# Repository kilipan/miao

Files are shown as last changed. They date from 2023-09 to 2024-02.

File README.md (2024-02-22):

# MIAO (喵) ch552t MCU board

### Changelog
2023-09-29 initial commit  
2023-09-30 fixed pinout to correspond to Xiao, added jumper to choose between RX/CS on pin 8, completely rerouted

| :zap: The hardware design is tested and confirmed working as of the latest commit. Nevertheless I cannot guarantee anything. **Use at your own risk!** |
|---|

## About
MIAO is a cheap drop-in replacement for the Seeeduino Xiao series.

喵 is the Hanzi for "miāo", which is Mandarin for "meow".

The board is available in two variants:
- A super cheap, hand-solderable version in `hw_handsolder` (since castellated holes are expensive, this version doesn't support them.)
- A cheap, pcba version in `hw_pcba`, featuring castellated holes

## Pictures
Renders of the handsolderable version and a screenshot of the schematic can be unfolded below.

<details>
<summary> Front view render </summary>

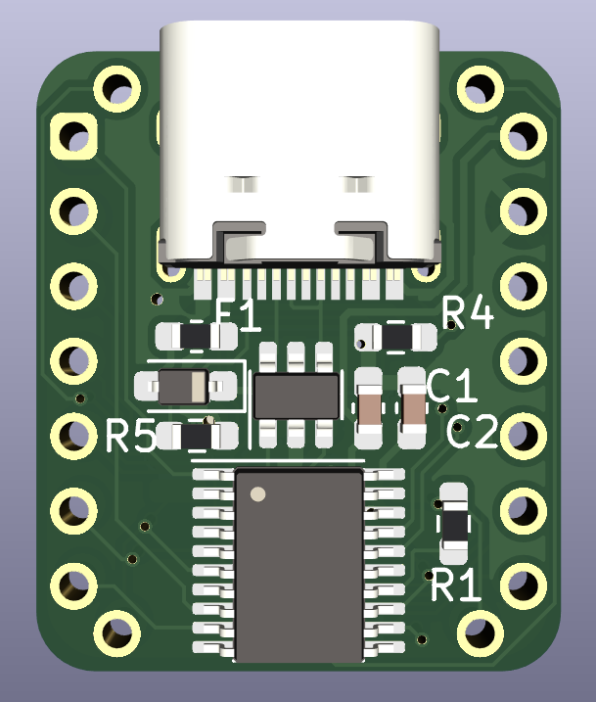
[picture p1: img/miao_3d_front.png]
miaofront


</details>
<details>
<summary> Back view render </summary>

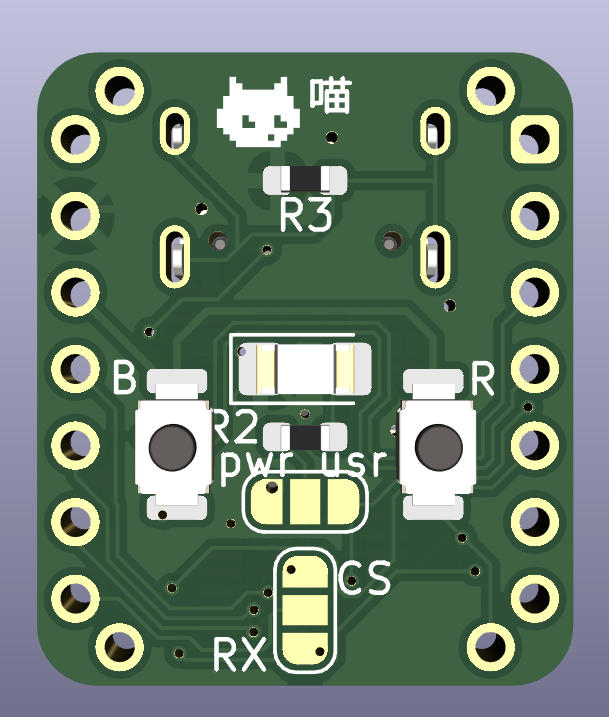
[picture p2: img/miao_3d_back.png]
miaoback


</details>
<details>
<summary> Schematic </summary>

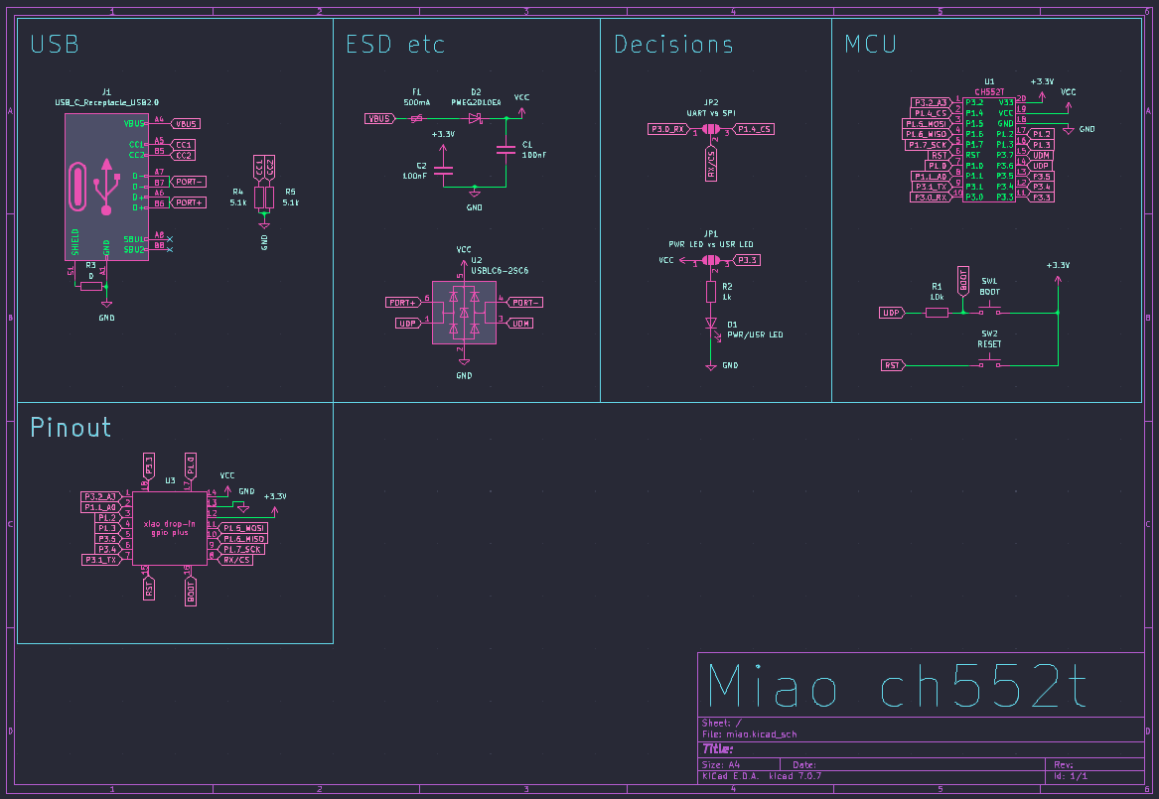
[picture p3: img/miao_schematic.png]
miaoschematic


</details>

# Features
MIAO features:
- Utilizes wch's ch552t microcontroller, which at the time of writing costs a few dozen cents! 
- SPI and UART pins in the same places as Xiao (use jumper to choose between RX/CS on pin 8)
- 2 Analogue pins
- 4 additional broken out pins (not pads!) compared to the Xiao boards:
  - 2 free GPIOs
  - reset pin (pull HIGH for reset)
  - boot pin (pull HIGH for entering bootloader)
- Full ESD protection incl. protection against reverse current and overcurrent
- Top-mount USB port for maximum drop-in-ability
- Optional power or user led (on the backside for the handsolderable version; bridge left and middle part of jumper for always-on, middle and right for user controllable via P3.3)
- Optional reset and bootloader buttons (on the backside for the handsolderable version)
- Optional footprint for connecting USB Shield to GND in a way that fits your application
- Cute pixel cat on the back! 🐱

# Availability
As production files are open sourced, you can get these manufactured at your favorite PCB-manufacturer. Alternatively, [keeb.supply](https://keeb.supply/) is selling the PCBA version usage-ready for a great price! Thanks guys! <3
Non-affiliate link: [Miao page on keeb.supply](https://keeb.supply/products/miao)

# BOM (handsolder only)
**This BOM is for the handsolderable version only.** For the PCBA version please refer to the given files.

| Amount | Part | LCSC part number | Silkscreen Reference | Comment |
|---:|:-----|:---|:---|:---|
| 1 | ch552t microcontroller | [C111367](https://www.lcsc.com/product-detail/USB-ICs_WCH-Jiangsu-Qin-Heng-CH552T_C111367.html) | U1 | |
| 1 | top-mount USB-C receptacle | [C2765186](https://www.lcsc.com/product-detail/_SHOU-HAN-_C2765186.html) | [none] | |
| 1 | SOT-23 ESD protection diode | [C6807798](https://www.lcsc.com/product-detail/_FUXINSEMI-_C6807798.html) | U2 | |
| 1 | SOD-323 Schottky diode | [C193668](https://www.lcsc.com/product-detail/_Nexperia-_C193668.html) | D2 | |
| 1 | 0603 Fuse | [C311055](https://www.lcsc.com/product-detail/_AEM-_C311055.html) | F1 | |
| 1 | 0603 10kΩ Resistor | [C25804](https://www.lcsc.com/product-detail/_UNI-ROYAL-Uniroyal-Elec-_C25804.html) | R1 | |
| 2 | 0603 5.1kΩ Resistor | [C23186](https://www.lcsc.com/product-detail/_UNI-ROYAL-Uniroyal-Elec-_C23186.html) | R4, R5 | |
| 2 | 0603 100nF Capacitors | [C384773](https://www.lcsc.com/product-detail/Multilayer-Ceramic-Capacitors-MLCC-SMD-SMT_Walsin-Tech-Corp-0603X334K100CT_C384773.html) | C1, C2 | Take care, these need to be soldered in vertically, as indicated by the small dashes on the silkscreen! |
| [1] | [optional] 1kΩ Resistor | [C21190](https://www.lcsc.com/product-detail/_UNI-ROYAL-Uniroyal-Elec-_C21190.html) | R2 | on the backside |
| [2] | [optional] push buttons | [C115357](https://www.lcsc.com/product-detail/_ALPSALPINE-_C115357.html) | B, R | on the backside |
| [1] | [optional] LED | [C434442](https://www.lcsc.com/product-detail/_Yongyu-Photoelectric-_C434442.html) | D1 | on the backside |

# Firmware
The project is inspired by and designed for usage with
[semickolon](https://github.com/semickolon/)'s
[FAK firmware](https://github.com/semickolon/fak/), but it's obviously not
limited to that! Refer to the ch552t documentation and the many other ch55x
projects for more details.

# License
The hardware design is licensed under the CERN-OHL-v2-S license, so feel free
to look at the sources and remix to your heart's content! :)

# Thanks
- semickolon for creating FAK, inspiring the project and helping with design considerations
- 0xCB for open-sourcing the [Helios](https://github.com/0xCB-dev/0xCB-Helios/) and providing inspiration for the ESD stuff
- the Clacktales community for their continued support, discussion, and interest in the project
- Pete Johanson for noticing and pointing out the pinout mix-up in the initially commited version

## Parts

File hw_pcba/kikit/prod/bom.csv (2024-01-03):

Comment | Designator | Footprint | LCSC
5.1k | R4,R5 | Resistor_SMD:R_0402_1005Metric | C25905
1k | R2 | Resistor_SMD:R_0402_1005Metric | C11702
~ | U1 | Package_SO:TSSOP-20_4.4x6.5mm_P0.65mm | C111367
PWR/USR LED | D1 | LED_SMD:LED_0402_1005Metric | C130724
RESET | SW2 | Button_Switch_SMD:SW_Push_SPST_NO_Alps_SKRK | C115357
10k | R1 | Resistor_SMD:R_0402_1005Metric | C25744
PMEG2010EA | D2 | Diode_SMD:D_0402_1005Metric | C2837790
BOOT | SW1 | Button_Switch_SMD:SW_Push_SPST_NO_Alps_SKRK | C115357
100nF | C1,C2 | Capacitor_SMD:C_0402_1005Metric | C1525
0 | R3 | Resistor_SMD:R_0402_1005Metric | C17168
USBLC6-2SC6 | U2 | Package_TO_SOT_SMD:SOT-23-6 | C2687116
USB_C_Receptacle_USB2.0 | J1 | Connector_USB:USB_C_Receptacle_HRO_TYPE-C-31-M-12 | C2765186
500mA | F1 | Fuse:Fuse_0402_1005Metric | C210357

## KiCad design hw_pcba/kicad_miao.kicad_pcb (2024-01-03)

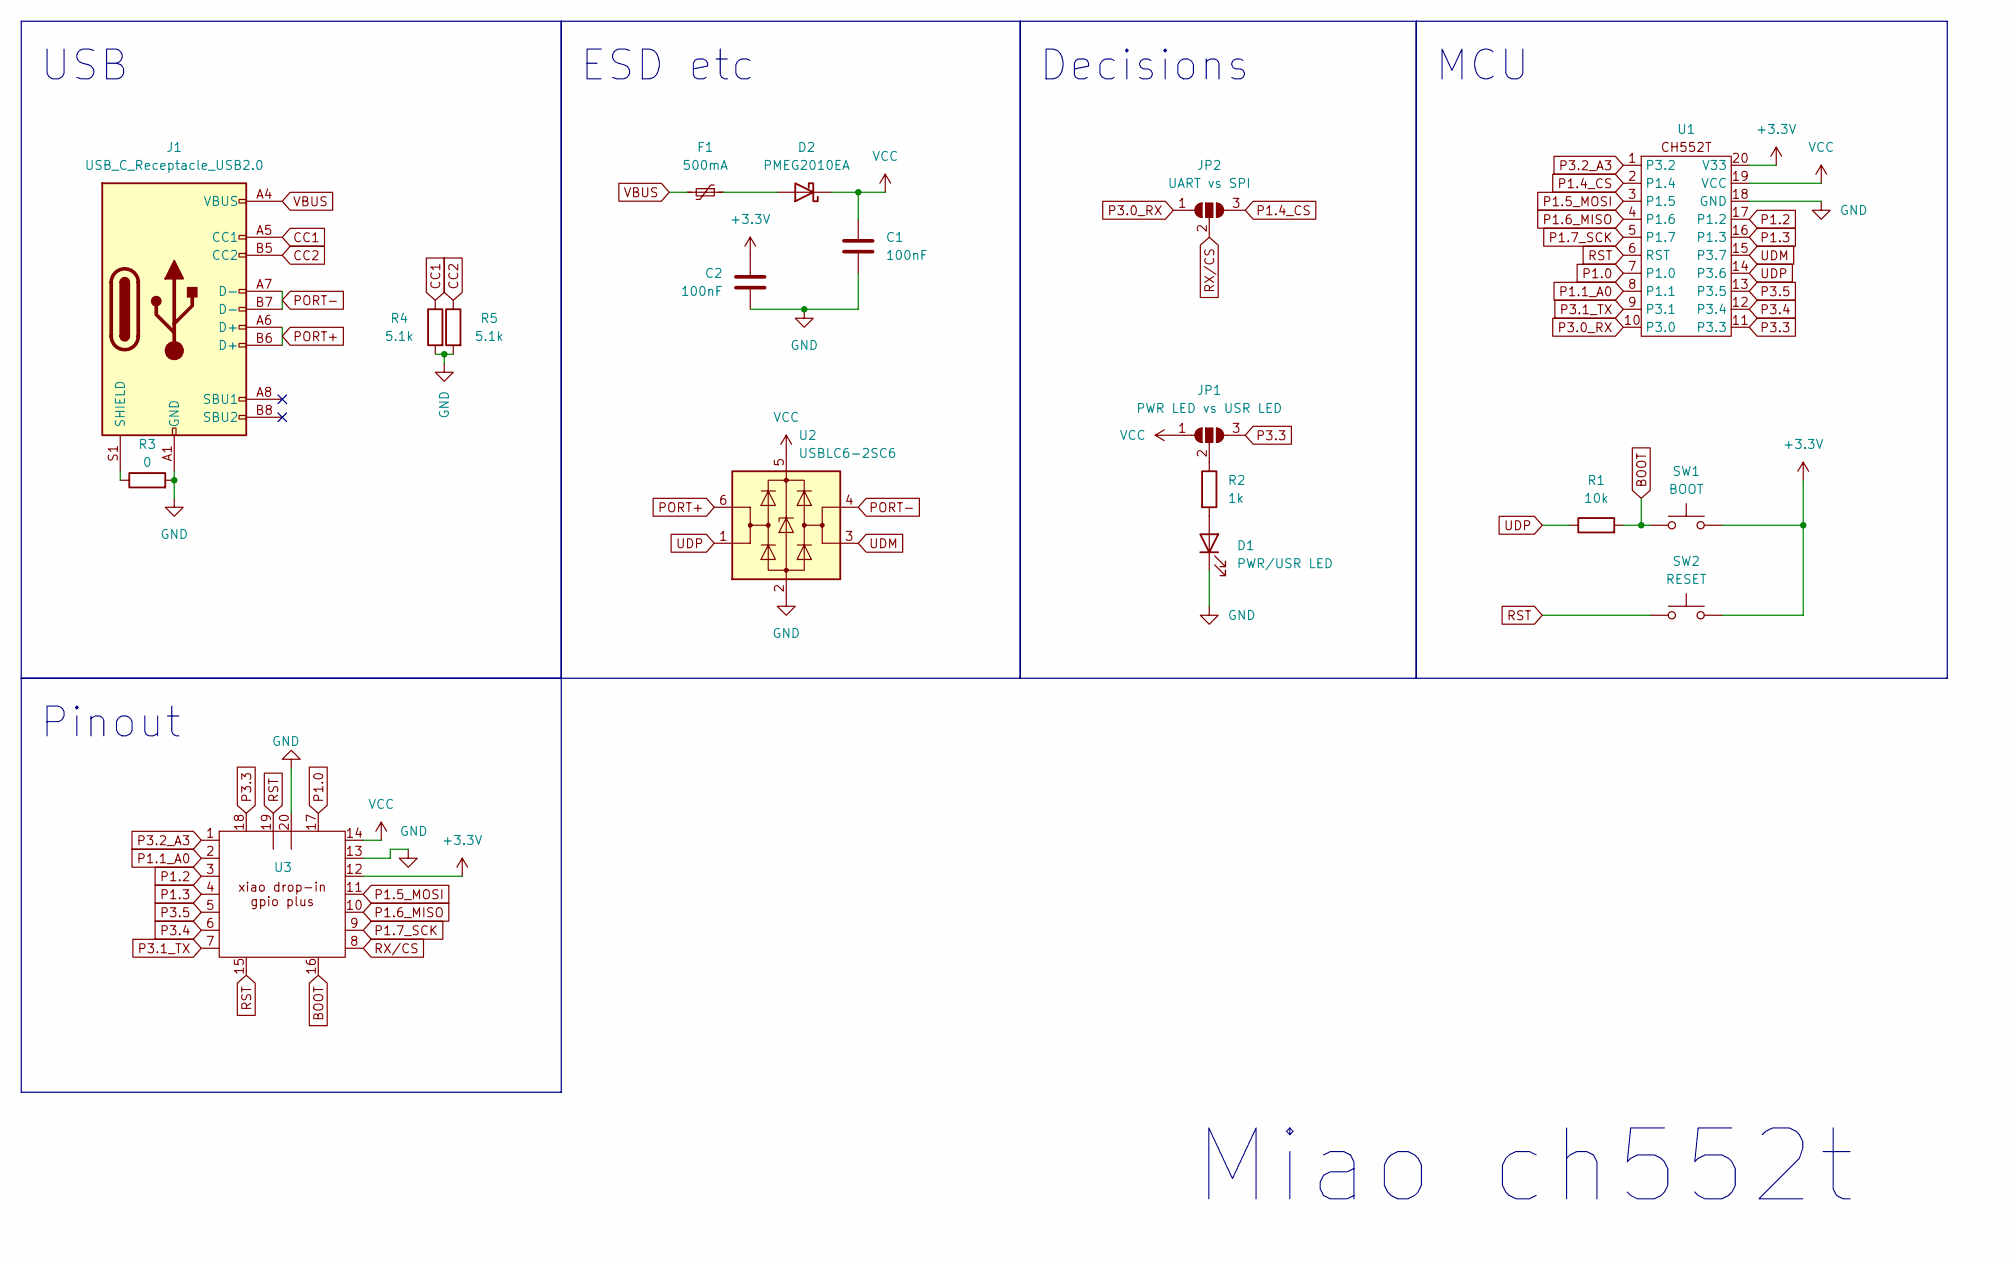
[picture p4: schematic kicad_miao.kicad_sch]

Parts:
C1, C2: 100nF; C_0402_1005Metric; LCSC C1525
D1: PWR/USR LED; LED_0402_1005Metric; LCSC C130724
D2: PMEG2010EA; D_0402_1005Metric; LCSC C2837790
F1: 500mA; Fuse_0402_1005Metric; LCSC C210357
J1: USB_C_Receptacle_USB2.0; USB_C_Receptacle_HRO_TYPE-C-31-M-12; JLCPCB_CORRECTION 0; -1.35; 0
JP1: PWR LED vs USR LED; SolderJumper-3_P1.3mm_Open_RoundedPad1.0x1.5mm_NumberLabels
JP2: UART vs SPI; SolderJumper-3_P1.3mm_Open_RoundedPad1.0x1.5mm_NumberLabels
R1: 10k; R_0402_1005Metric; LCSC C25744
R2: 1k; R_0402_1005Metric; LCSC C11702
R3: 0; R_0402_1005Metric; LCSC C17168
R4, R5: 5.1k; R_0402_1005Metric; LCSC C25905
SW1: BOOT; SW_Push_SPST_NO_Alps_SKRK; LCSC C115357
SW2: RESET; SW_Push_SPST_NO_Alps_SKRK; LCSC C115357
U1: TSSOP-20_4.4x6.5mm_P0.65mm; JLCPCB_CORRECTION 0; 0; 270
U2: USBLC6-2SC6; SOT-23-6; JLCPCB_CORRECTION 0; 0; 270
U3: xiao_drop-in_gpio_usb_no_cutout; xiao_drop-in_gpio_plus_4_castellated

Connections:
+3.3V: C2.1, SW1.2, SW2.2, U1.20 (V33), U3.12
BOOT: R1.2, SW1.1, U3.16
CC1: J1.A5 (CC1), R4.1
CC2: J1.B5 (CC2), R5.1
GND: C1.2, C2.2, D1.1 (K), J1.A1 (GND), J1.A12 (GND), J1.B1 (GND), J1.B12 (GND), R3.2, R4.2, R5.2, U1.18 (GND), U2.2 (GND), U3.13, U3.20
unnamed: D1.2 (A), R2.2
unnamed: D2.2 (A), F1.1
unnamed: J1.S1 (SHIELD), R3.1
unnamed: JP1.2 (C), R2.1
P1.0: U1.7 (P1.0), U3.17
P1.1_A0: U1.8 (P1.1), U3.2
P1.2: U1.17 (P1.2), U3.3
P1.3: U1.16 (P1.3), U3.4
P1.4_CS: JP2.3 (B), U1.2 (P1.4)
P1.5_MOSI: U1.3 (P1.5), U3.11
P1.6_MISO: U1.4 (P1.6), U3.10
P1.7_SCK: U1.5 (P1.7), U3.9
P3.0_RX: JP2.1 (A), U1.10 (P3.0)
P3.1_TX: U1.9 (P3.1), U3.7
P3.2_A3: U1.1 (P3.2), U3.1
P3.3: JP1.3 (B), U1.11 (P3.3), U3.18
P3.4: U1.12 (P3.4), U3.6
P3.5: U1.13 (P3.5), U3.5
PORT+: J1.A6 (D+), J1.B6 (D+), U2.6 (I/O1)
PORT-: J1.A7 (D-), J1.B7 (D-), U2.4 (I/O2)
RST: SW2.1, U1.6 (RST), U3.15, U3.19
RX/CS: JP2.2 (C), U3.8
UDM: U1.15 (P3.7), U2.3 (I/O2)
UDP: R1.1, U1.14 (P3.6), U2.1 (I/O1)
VBUS: F1.2, J1.A4 (VBUS), J1.A9 (VBUS), J1.B4 (VBUS), J1.B9 (VBUS)
VCC: C1.1, D2.1 (K), JP1.1 (A), U1.19 (VCC), U2.5 (VBUS), U3.14

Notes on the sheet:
MCU
Miao ch552t
USB
Decisions
ESD etc
Pinout

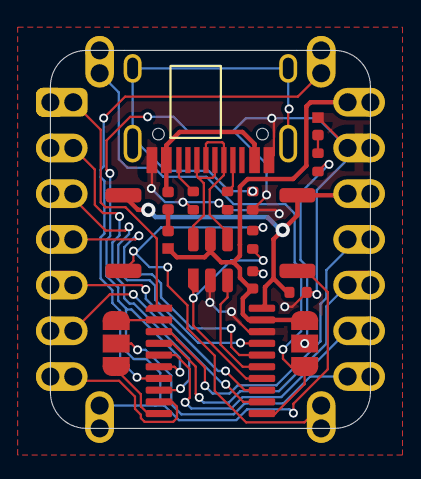
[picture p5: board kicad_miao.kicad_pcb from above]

Board: 2 copper layers, 17.8 x 21.0 mm, 18 parts (0 on the bottom side), 31 nets.

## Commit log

2023-09-28 add kicad runtime files to gitignore
2023-09-30 hopefully fix pin-out errors to add more compat
    [miao.kicad_pcb, miao.kicad_sch]
2023-10-01 update README, clean-up schematic
    [miao.kicad_sch]
2023-11-20 Add BOM, change t
2023-11-20 Add silkscreen references and comments to BOM
2024-01-03 update with pcba version, reflect in readme
    [bom.csv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]
2024-01-05 add kicad symbol and footprint
